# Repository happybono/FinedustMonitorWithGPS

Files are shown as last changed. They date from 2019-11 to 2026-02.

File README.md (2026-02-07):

# FinedustMonitorWithGPS
Fine dust (air pollution) monitoring station. Air pollution monitoring channel updates once every minute with PM 10.0 and PM 2.5 readings from the Nova PM (SDS011) Sensor. Also includes real-time location tracking capabilities using the GY-NEO6MV2 GPS Sensor.

<div align="center">
 



</div>
                                                                                                         
 
### Please note
> [!NOTE]
> This project requires a GY-NEO6MV2 GPS Sensor. For a project that does not require a GPS module, please visit the following link : https://github.com/happybono/FinedustMonitor
 
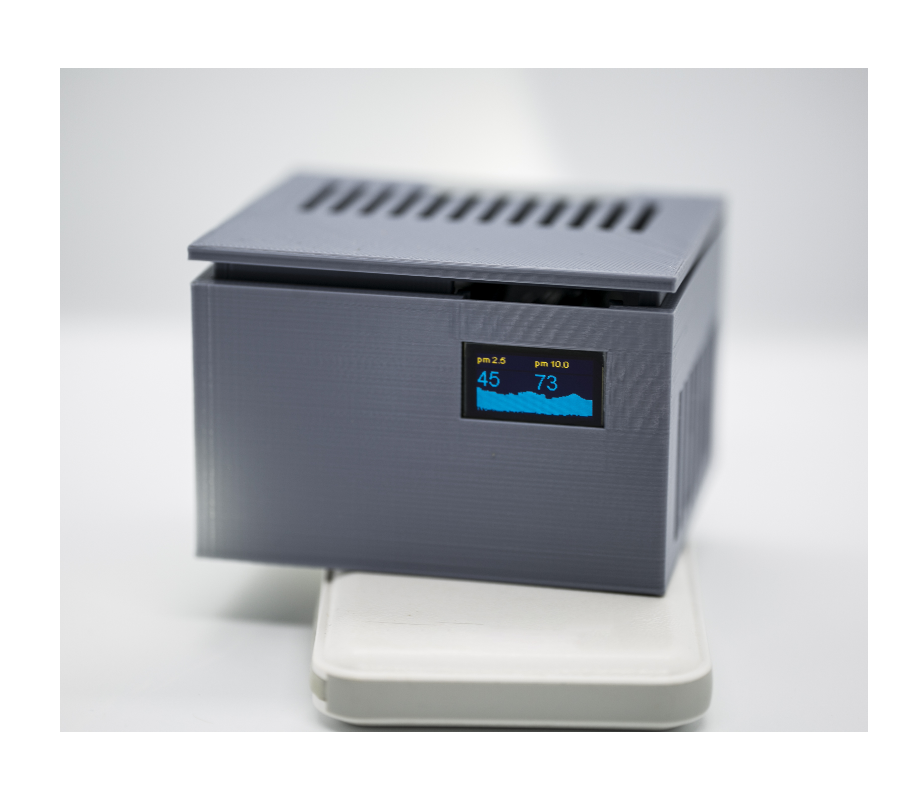
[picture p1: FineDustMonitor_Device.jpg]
Final Product


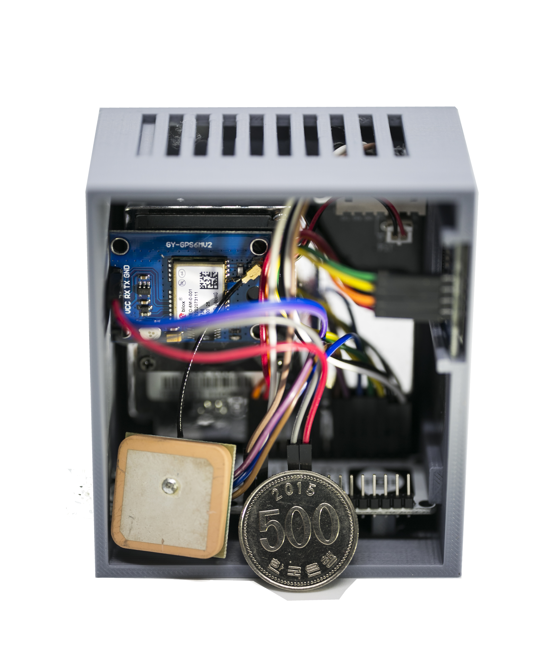
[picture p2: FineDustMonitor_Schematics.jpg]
Final Circuit


## What's New
<details>
<summary>Click to Expand</summary>
  
### v1.0
#### November 24, 2019
> [Initial Release.](https://github.com/happybono/FinedustMonitorWithGPS/commit/aa9cbf7b85308d91ce775d71c36cdd96b5740529)

#### December 16, 2019
> [Read GPS data from ThingSpeak and displays it on Google Maps using ESP12e NodeMCU and GPSNeo6MV2 Module.](https://github.com/happybono/FinedustMonitorWithGPS/blob/master/Maps/GoogleMaps.html "FinedustMonitorWithGPS/Maps/GoogleMaps.html")

#### December 25, 2019
> [Now supports [Channel Status Updates] in ThingSpeak](https//thingspeak.com/channels/920137)  Updated [FinedustMonitorWithGPS.ino](https//github.com/happybono/FinedustMonitorWithGPS/commit/01367946fd2dc10b39b39dec19309892311e92ea "/FinedustMonitorWithGPS/FinedustMonitorWithGPS.ino"), [server.ino](https://github.com/happybono/FinedustMonitorWithGPS/commit/3c3a89e9d8a4e45f591379dc96e2e7b67e15914d "/FinedustMonitorWithGPS/server.ino")

#### December 29, 2019
> [Various bugs fixed.](https://github.com/happybono/FinedustMonitorWithGPS/commit/d6d25d7cf4dc4b91f174259ea1e473220ab79385)

#### January 20, 2020
> ["Latest PM sensor readings" plugin added in ThingSpeak.](https://github.com/happybono/FinedustMonitorWithGPS/tree/master/Plugins/StatusUpdates)

### v2.0
#### January 21, 2020
> [Displays additional information](https://github.com/happybono/FinedustMonitorWithGPS/blob/2882255266a72da46fa2a047b24e56b23cf94838/Plugins/StatusUpdates/CSS.css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) ([temperature](https://github.com/happybono/FinedustMonitorWithGPS/blob/2882255266a72da46fa2a047b24e56b23cf94838/Plugins/StatusUpdates/JavaScript.html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), [latitude](https://github.com/happybono/FinedustMonitorWithGPS/blob/2882255266a72da46fa2a047b24e56b23cf94838/Plugins/StatusUpdates/JavaScript.html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), [longitude](https://github.com/happybono/FinedustMonitorWithGPS/blob/2882255266a72da46fa2a047b24e56b23cf94838/Plugins/StatusUpdates/JavaScript.html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)) in the[ "Latest PM sensor readings" plugin.](https://github.com/happybono/FinedustMonitorWithGPS/tree/master/Plugins/StatusUpdates)<br><br>
>Various bugs fixed.

#### January 24, 2020
> [Added Reverse Geocoding function in Google Maps.](https://github.com/happybono/FinedustMonitorWithGPS/blob/95abbb8ae55be63581fe9892d7d798f0c71eb8e6/Maps/GoogleMaps.html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)<br><br>
> [Optimized loading time for Google Maps.](https://github.com/happybono/FinedustMonitorWithGPS/blob/95abbb8ae55be63581fe9892d7d798f0c71eb8e6/Maps/GoogleMaps.html)

#### Jaunary 25, 2020
> [Added an onclick event to displayed marker in Google Maps.](https://github.com/happybono/FinedustMonitorWithGPS/blob/95abbb8ae55be63581fe9892d7d798f0c71eb8e6/Maps/GoogleMaps.html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)

#### February 05, 2020
> [Added VBA (Visual Basic for Applications) code for reverse geocoding support in Microsoft Excel.](https://github.com/happybono/FinedustMonitorWithGPS/blob/master/Maps/Excel/GEOSage.vb)<br>
> Powered by MSExcel logo<br><br>
> [Added Javascript (.gs) code for reverse geocoding support in Google Sheets.](https://github.com/happybono/FinedustMonitorWithGPS/blob/master/Maps/Excel/GoogleSheets.gs) ([ⓒ 2018 Christos Samaras](https://myengineeringworld.net/2018/08/geocoding-reverse-gas.html))<br>
> [Added Javascript (.gs) code for reverse geocoding macro support in Google Sheets.](https://github.com/happybono/FinedustMonitorWithGPS/blob/master/Maps/Excel/GoogleSheetsGeocodingMacro.gs) ([ⓒ 2016 - 2017 Max Vilimpoc](https://github.com/nuket/google-sheets-geocoding-macro))<br>
> Powered by Google logo

#### February 19, 2020
> [Optimized performance for data processing.](https://thingspeak.com/channels/920137/api_keys)

#### February 20, 2020
> ["Email Alert" function added as a ThingSpeak Analysis plug-in.](https://github.com/happybono/FinedustMonitorWithGPS/blob/master/Plugins/Email/EmailNotifier.m) 

#### February 26, 2020
> [Performance improvements (up to 2× as faster than before) in the ADDRGEOCODE function in GEOSage.vb.](https://github.com/happybono/FinedustMonitorWithGPS/blob/master/Maps/Excel/GEOSage.vb#L86) <br><br>
> [Now supports Unicode using the Microsoft ActiveX Data Objects Library in the ADDRGEOCODE function in GEOSage.vb.](https://github.com/happybono/FinedustMonitorWithGPS/blob/master/Maps/Excel/GEOSage.vb#L115)

#### February 27, 2020
> [Added GEOSage sample files.](https://github.com/happybono/FinedustMonitorWithGPS/tree/master/Maps/Excel) <br>
> GEOSage sample includes Excel files that use demonstration data using Google Maps Geocoding API Key. The 
API key used in this project for geocoding and reverse geocoding features is not provided for your use. 
The mock data demonstrates all functions with static result values as the Google Maps geocoding API Key and 
VBA Add-in code is not included in the GEOSage sample.

#### March 03, 2020
> [Added GEOSage.bas file to support direct import from Microsoft Excel.](https://github.com/happybono/FinedustMonitorWithGPS/blob/master/Maps/Excel/GEOSage.bas)

#### May 28, 2020
> [Added 3D modeled housing file.](https://github.com/happybono/FinedustMonitorWithGPS/blob/master/3DModels/SDS011-Housing.stl)

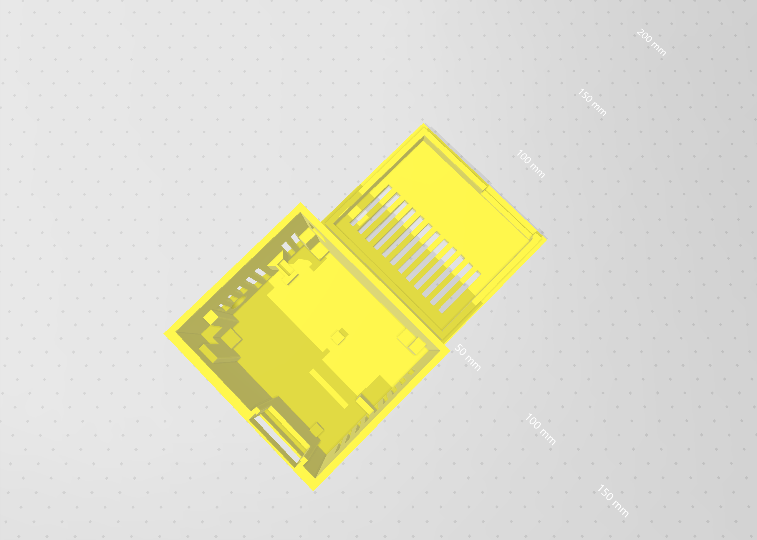
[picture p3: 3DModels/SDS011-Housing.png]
3DModel
> 

#### June 04, 2020
> Attached a programmed NFC Tag Sticker for faster and more convenient access to the ThingSpeak dashboard.

#### June 11, 2020
> [Fine dust (PM 2.5 and PM 10.0) 3D visualization bar charts added on the ThingSpeak dashboard.](https://github.com/happybono/FinedustMonitorWithGPS/tree/master/Plugins/Visualizations)

#### June 12, 2020
> [Various bugs fixed related to fine dust (PM 2.5 and PM 10.0) 3D visualization bar charts.](https://github.com/happybono/FinedustMonitorWithGPS/tree/master/Plugins/Visualizations)

#### June 16, 2020
> [Supports multiple series (PM 2.5 & PM 10.0) chart as a ThingSpeak plugin.](https://github.com/happybono/FinedustMonitorWithGPS/tree/master/Plugins/MultiSeriesChart)

#### June 17, 2020
> Various bugs fixed.

#### June 25, 2020
> [Major improvements to the "Latest PM sensor readings" plugin.](https://github.com/happybono/FinedustMonitorWithGPS/tree/master/Plugins/StatusUpdates)

#### June 27, 2020
> [Various improvements to the "Latest PM sensor readings" plugin.](https://github.com/happybono/FinedustMonitorWithGPS/tree/master/Plugins/StatusUpdates)<br><br>
> [Several bugs fixed related to the "Latest PM sensor readings" plugin.](https://github.com/happybono/FinedustMonitorWithGPS/tree/master/Plugins/StatusUpdates)

#### July 03, 2020
> [Various bugs fixed related to fine dust (PM 2.5 and PM 10.0) 3D visualization bar charts.](https://github.com/happybono/FinedustMonitorWithGPS/tree/master/Plugins/Visualizations)

#### July 08, 2020
> [Fixed a defect that prevented the measurement value from being uploaded under certain environmental conditions.](https://github.com/happybono/FinedustMonitorWithGPS/blob/master/FinedustMonitorWithGPS/FinedustMonitorWithGPS.ino)

#### July 15, 2020
> [Temperature 3D visualization bar charts added on the ThingSpeak dashboard.](https://github.com/happybono/FinedustMonitorWithGPS/tree/master/Plugins/Visualizations)

#### December 07, 2020
> [Applied font styling to the "Latest PM sensor readings" plugin.](https://github.com/happybono/FinedustMonitorWithGPS/tree/master/Plugins/StatusUpdates)<br><br>
> [Adjusted code formatting and indentation (if applicable).](https://github.com/happybono/FinedustMonitorWithGPS/tree/master/Plugins/StatusUpdates)

#### December 08, 2020
> [Improved readability of symbols and measurement units.](https://github.com/happybono/FinedustMonitorWithGPS/tree/master/Plugins/StatusUpdates)

#### December 27, 2020
> ["Geocoder failed due to: ZERO_RESULTS" error output changed. The error message is no longer displayed in the pop-up message box, will display it in the "Latest PM sensor readings" plugin as text.](https://github.com/happybono/FinedustMonitorWithGPS/tree/master/Plugins/StatusUpdates)

#### December 30, 2020
> [Various bugs fixed.](https://github.com/happybono/FinedustMonitorWithGPS/blob/master/FinedustMonitorWithGPS/FinedustMonitorWithGPS.ino)

### v3.0
#### January 11, 2021
> [Now supports notifications through Twitter using the Thingtweet plugin from the ThingSpeak platform.](https://www.twitter.com/Jeongwang3D_AQI)

#### March 28, 2021
> [Now supports analyzing and drawing charts on https://thingspeak.com/channels/1184617. Shown are the weekly average values (PM 2.5, PM 10.0, and temperature) using data from https://thingspeak.com/channels/920137.](https://github.com/happybono/FinedustMonitorWithGPS/commit/a3c0b472f2549ebac2ff92c9009388211a50a09a)
 
#### April 22, 2021
> [Added Twitter timeline widget as a JavaScript-based plug-in.](https://github.com/happybono/FinedustMonitorWithGPS/tree/b334c427448ce27f469f366334dc8303b18c8db3/Plugins/TwitterTimeline)

#### August 23, 2021
> [Improvements have been made to the "Email Alert" function.](https://github.com/happybono/FinedustMonitorWithGPS/blob/master/Plugins/Email/EmailNotifier.m) 
  
#### April 16, 2022
> [Update to support tightened the rules around query parameters in the ThingSpeak platform.](https://github.com/happybono/FinedustMonitorWithGPS/commit/42160c6df4b8b7759f6b9ec417fe9858e86d11a1)

#### March 26, 2025
> [Applied text flipping animation to the "Latest PM sensor readings" plugin.](https://github.com/happybono/FinedustMonitorWithGPS/tree/master/Plugins/StatusUpdates)
</details>

#### December 25, 2025
> [Changed image source to blog URL to resolve imread() access issue.](https://github.com/happybono/FinedustMonitorWithGPS/commit/5cb7dc2b1ca8dca2396561faf552fcb2dcdea0da)

## Specifications
### Scenarios
* Measuring the fine dust contamination level in the air in real time. The value is displayed on the OLED Screen and updated every second.
* Measuring the current temperature.
* Track and update device location in real time.
* Reading GPS data (longitude, latitude) from [ThingSpeak](https://thingspeak.com/channels/920137) and display it using [Google Maps](https://www.google.com/maps/) with the [Maps JavaScript API](https://developers.google.com/maps/documentation/javascript/tutorial).
* Refining data and synchronizing with the web-based cloud service. (i.e. [ThingSpeak](https://www.thingspeak.com/), [Plaive](https://plaive.10make.com/))
* Refining the average calculated data to separate channels on the web-based cloud service. (i.e. [ThingSpeak](https://www.thingspeak.com/), [Plaive](https://plaive.10make.com/))
* Using reverse geocoding to convert a location (latitude, longitude) measured by the device to a readable address.
* Using [Microsoft Excel](https://products.office.com/get-started-with-office-2019) to process a batch of locations (latitude, longitude). Data can be exported in CSV format from [ThingSpeak](https://www.thingspeak.com/) to open in Excel.

#### What is Reverse Geocoding?
> Reverse geocoding is the process of back (reverse) coding of a point location (latitude, longitude) to a readable address or place name. This permits the identification of nearby street addresses, places, and/or areal subdivisions such as neighbourhoods, counties, states, or countries.

[More information on reverse geocoding with Google Maps JavaScript API](https://developers.google.com/maps/documentation/geocoding/intro#ReverseGeocoding)
<br>
Powered by Google logo

### Connections
* 1 x Micro-USB

### Wireless
* IEEE 802.11 b/g/n Wi-Fi technology.

### Battery life 
* Up to 35 hours (1 day and 12 hours) of typical device usage.
* Testing consisted of full-time active use until complete battery discharge. 
* Wi-Fi was connected to a network.
* Syncs data once every minute with PM 10.0 and PM 2.5 readings from the Nova PM (SDS011) Sensor, Temperature reading from the DS18B20 Temperature Sensor, and GPS-positioned reading values (longitude, latitude) from the GY-NEO6MV2 GPS Sensor.
* Battery life may vary significantly with settings, usage, and other factors.

## Apparatus (Equipment)
### Platform
* NodeMCU ESP8266-12E

### SDS011 Dust Sensor
* Soldering required
* D1 : TX of SDS011

### 0.96" SSD1306 I2C OLED Display 
* Soldering required
* D3 : Data, D2 : Clock

### GY-NEO6MV2 GPS Sensor
* Soldering required
* D6 & D7 : TX & RX of GY-NEO6MV2 respectively.

### DS18B20 Temperature Sensor (Thermometer)
* Soldering required
* D4 : Data

### iriver Tactile (SPB-10000) Portable Battery
* USB Port : Power
* Micro-USB : Charging Port
* Dimension : 63.3 mm (W) × 90.7 mm (D) × 22.3 mm (H)
* Weight : 180 g
* Input : DC-5V / 2A (Micro 5-Pin)
* Output : DC-5V / 2A (2 USB ports)
* Capacity : 10,000 mAh

### Circular NFC Tag Sticker (N-Tag 216)
* Size : 25.0 mm
* Capacity : 926 Byte
* This should be programmed to automatically open the ThingSpeak Dashboard when the NFC-capable device comes into contact with the NFC Tag Sticker.
* https://www.amazon.com/GoToTags-Blank-White-Metal-NFC/dp/B00TRL774A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

## Schematics
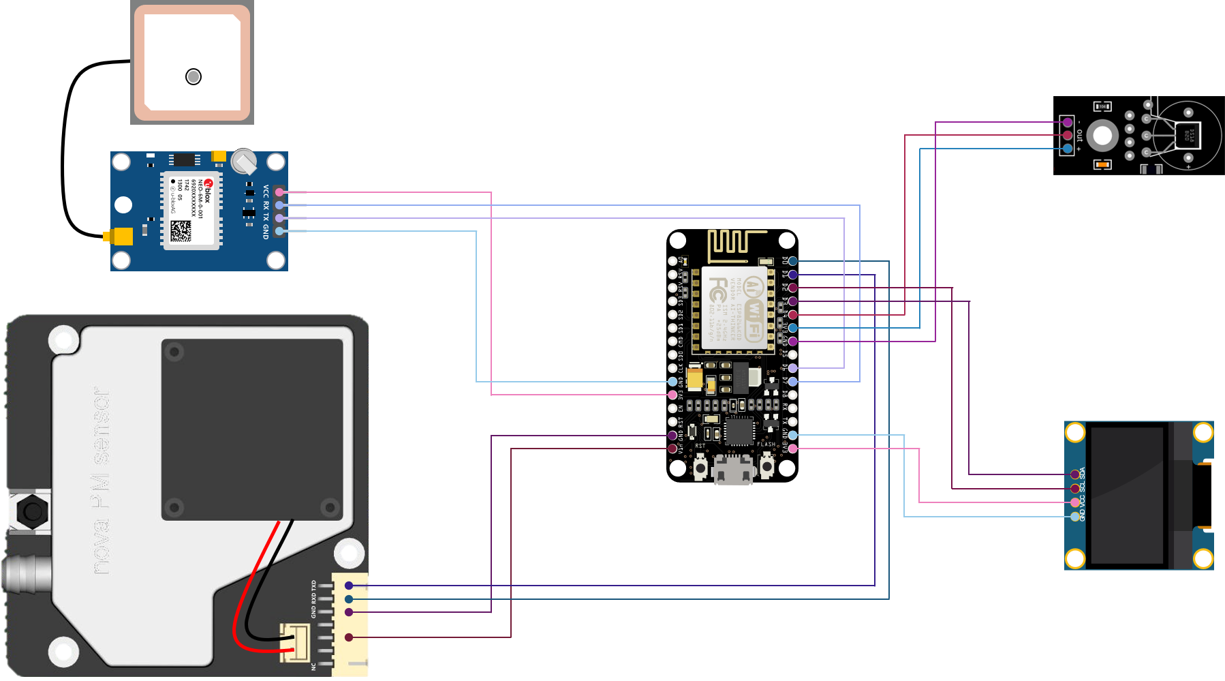
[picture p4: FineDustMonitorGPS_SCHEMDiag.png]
Schematics Diagram


## Data Refinement / Synchronization
### ThingSpeak
* ThingSpeak (https://thingspeak.com/channels/920137)
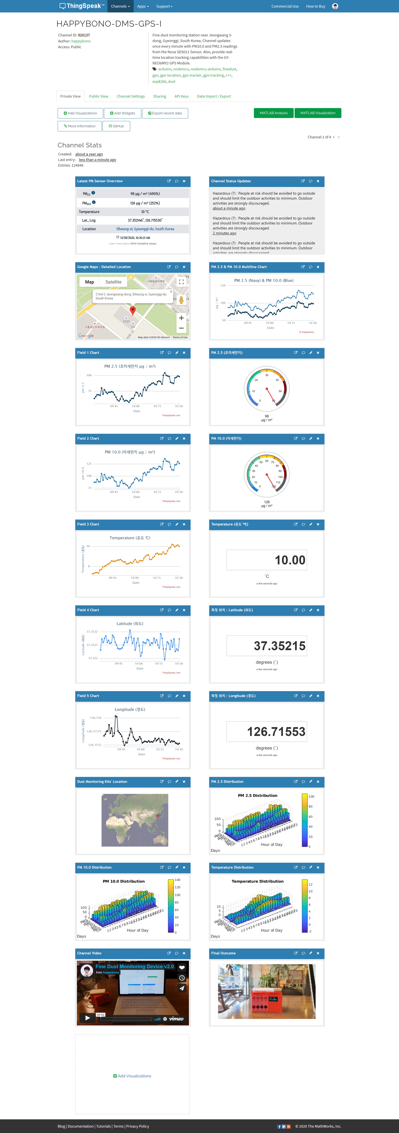
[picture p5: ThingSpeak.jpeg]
ThingSpeak Screenshot

  
### Plaive
* Plaive (https://plaive.10make.com/)
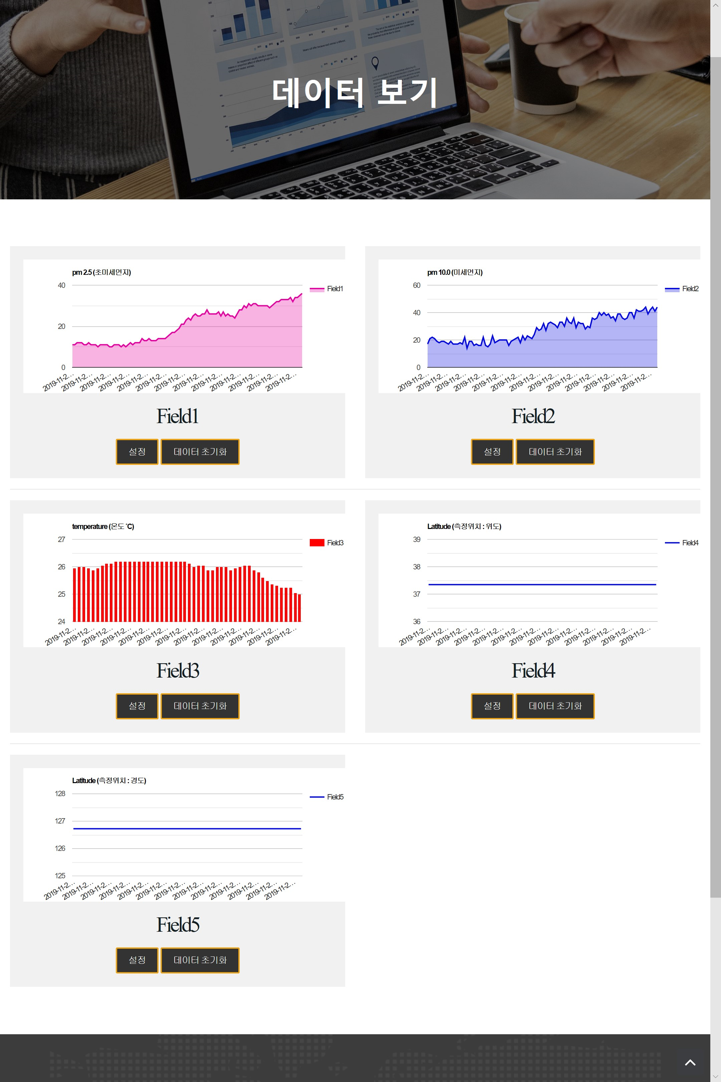
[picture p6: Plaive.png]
Plaive Screenshot


## Libraries Used
### DallasTemperature
This library supports the following devices :

DS18B20 <br>
DS18S20 - Please note there appears to be an issue with this series. <br>
DS1822 <br>
DS1820 <br>
MAX31820 <br>
https://github.com/milesburton/Arduino-Temperature-Control-Library

### TinyGPSPlus (TinyGPS++) for GY-NEO6MV2
A new, customizable Arduino NMEA parsing library. A NEW Full-featured GPS/NMEA Parser for Arduino TinyGPS++ is a new Arduino library for parsing NMEA data streams provided by GPS modules.

Like its predecessor, TinyGPS, this library provides compact and easy-to-use methods for extracting position, date, time, altitude, speed, and course from consumer GPS devices.<br>
https://github.com/mikalhart/TinyGPSPlus

### SSD1306 (0.96") OLED Display
This is a driver for SSD1306 128x64, 128x32, 64x48, and 64x32 OLED displays running on the Arduino / ESP8266 & ESP32 and mbed-os platforms. Can be used with either the I2C or SPI version of the display. <br>
https://www.github.com/ThingPulse/esp8266-oled-ssd1306

### RunningMedian
Arduino library to determine the running median utilizing a circular buffer. <br>
https://github.com/RobTillaart/Arduino/tree/master/libraries/RunningMedian

Running Median looks like a running average with a small but important twist.   
**Running average** **averages** the last `N` samples, while the **running median** takes the last `N` samples, **sorts them, and takes the middle one, or the average of the middle two**.

> [!Important]
> Important differences between **running average** and **running median** :
> * **Running median** will return real data (e.g., a real sample from a sensor) if one uses an odd size of the buffer (preferred). Running average may return a value that is never sampled.
> * **Running median** will give zero weight to outliers, and 100% to the middle sample, whereas running average gives the same weight to all samples.
> * **Running median** will often give constant values for some time.
> * As one knows, the values in the buffer, one can predict to some extent how much the next samples will change the **running median**.
> * **Running median** is a bit harder as one needs to keep the values to remove the oldest and keep them sorted to be able to select the median.

## References
* Christos Samaras 2018, Geocoding & Reverse Geocoding Functions In Google Sheets, My Engineering World, Christos Samaras, viewed 5 February 2020, <https://myengineeringworld.net/2018/08/geocoding-reverse-gas.html>.
* Max Vilimpoc 2019, nuket/google-sheets-geocoding-macro, GitHub, Nuket. viewed 5 February 2020, <https://github.com/nuket/google-sheets-geocoding-macro>.
* Rob Tillaart 2018, RobTillaart/Arduino, GitHub, RobTillaart, viewed 23 February 2020, <https://github.com/RobTillaart/Arduino/blob/master/libraries/RunningMedian/RunningMedian.cpp>.
* ThingPulse 2020, ThingPulse/esp8266-oled-ssd1306, GitHub, ThingPulse, viewed 24 November 2019, <https://github.com/ThingPulse/esp8266-oled-ssd1306>.

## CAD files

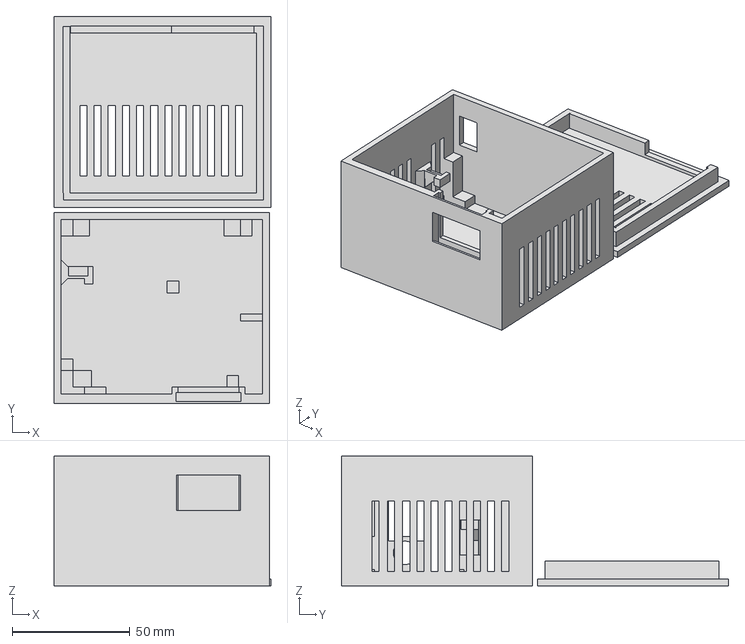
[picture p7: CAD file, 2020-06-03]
3DModels/SDS011-Housing.3mf
92.0 x 164.2 x 55.0 mm

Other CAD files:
3DModels/SDS011-Housing.stl

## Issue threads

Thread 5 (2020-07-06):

New Login Requirement for Free Accounts Using MATLAB Analysis

happybono, 2020-07-06:
For accounts with a free license, extended inactivity disables execution of MATLAB® Analysis. For a MATLAB Analysis App associated with TimeControl and React apps, you need to log in to ThingSpeak™ at least once every 60 days to ensure they continue to execute without interruption.

https://www.mathworks.com/help/thingspeak/release-notes.html
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

happybono, 2020-07-06:
For a MATLAB Analysis App associated with TimeControl and React apps, **you need to log in to ThingSpeak™ at least once every 60 days to ensure they continue to execute without interruption.**

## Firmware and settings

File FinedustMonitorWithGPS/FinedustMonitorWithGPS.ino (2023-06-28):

//
//    FILE: FinedustMonitorWithGPS.ino
//  AUTHOR: Jaewoong Mun (happybono@outlook.com)
// CREATED: November 19, 2019
//
// Released to the public domain
//

#include <TinyGPS++.h>
#include <SoftwareSerial.h>
TinyGPSPlus gps;
SoftwareSerial ss(12, 13);
SoftwareSerial dust(D1, D0, false, 256);            //RX, TX Communication
#include "RunningMedian.h"

RunningMedian pm25s = RunningMedian(19);
RunningMedian pm10s = RunningMedian(19);

char* ssid = "[Wi-Fi SSID]";
char* password = "[Wi-Fi Password]";
String api_key = "[ThingSpeak Write API Key]";

//#define PLAIVE_SERVER_ENABLE
#define THINGSPEAK_SERVER_ENABLE

boolean wifi_ready;
float map_x, map_y;
String s_map_x, s_map_y, status;
int pm25i, pm10i;

//초기 세팅 (Initialize.)
void setup() {
  Serial.begin(115200);
  dust.begin(9600);
  ss.begin(9600);
  setup_oled();
  wifi_ready = connect_ap(ssid, password);
  
  if (!wifi_ready) nowifi_oled();

  Serial.println("\nFinedust Sensor Box V3.2, 2022/04/16 HappyBono");
}


void got_dust(int pm25, int pm10) {                 //formula for dust sensor just use!!
  pm25 /= 10;
  pm10 /= 10;
  pm25s.add(pm25);
  pm10s.add(pm10);
  do_oled(pm25, pm10);                              //print pm25, pm10 in oled
}


//서버에 데이터 보내기 (Sending collected data to server.)
void do_interval() {
  if (wifi_ready) {
#ifdef PLAIVE_SERVER_ENABLE
    do_server_plaive(api_key, int(pm25s.getMedian()), int(pm10s.getMedian()), get_temperature(), s_map_x, s_map_y);
#else
#ifdef THINGSPEAK_SERVER_ENABLE
    Serial.println("dst: pm25=" + String(int(pm25s.getMedian())) + " / pm10=" + String(int(pm10s.getMedian())) + "/ s=" + String(status));
    do_server_thingspeak(api_key, int(pm25s.getMedian()), int(pm10s.getMedian()), get_temperature(), s_map_x, s_map_y, status);
#else
    do_server_default(api_key, int(pm25s.getMedian()), int(pm10s.getMedian()), get_temperature(), s_map_x, s_map_y);
#endif
#endif
  }                                                    //wifi is ok
}

unsigned long mark = 0;
boolean got_interval = false;

//아두이노가 반복적으로 작동하는 부분 (Where Arduino works repeatedly.)
void loop() {
  if (ss.available() <= 0) {
    // Serial.println("SIGNAL STATUS : WEAK");
    s_map_x = String(map_x, 6);
    s_map_y = String(map_y, 6);
  }
  else {
    while (ss.available() > 0) {
      //Serial.println("SIGNAL STATUS : GREAT");
      if (gps.encode(ss.read())) {
        //Serial.println("GPS READ");
        Serial.println(ss.read());
        if (gps.location.isValid()) {
          //Serial.println("LOCATION : GREAT");
          map_x = gps.location.lat();
          map_y = gps.location.lng();
          Serial.println(String(map_x, 6));
          Serial.println(String(map_y, 6));
        }
      }
      s_map_x = String(map_x, 6);
      s_map_y = String(map_y, 6);
      yield();
    }
  }
  while (dust.available() > 0) {
    do_dust(dust.read(), got_dust);
    yield();                                          //loop 에서 while 문을 사용하는 경우 yield 를 포함해주어야 합니다.

    //Serial.println(map_x);
    //Serial.print("pm 10 : ");
    //Serial.println(int(pm10s.getMedian()));

    /* AQI (실시간 대기질 지수) 등급 분류를 위한 코드입니다.
       실시간 대기질 기준 수치는 국제 표준인 WHO 대기질 수치 기준으로 계산하였습니다.

       http://www.euro.who.int/__data/assets/pdf_file/0005/78638/E90038.pdf
       https://airnow.gov/index.cfm?action=aqibasics.aqi */


    // 초미세먼지 AQI (실시간 대기질 지수) 등급을 분류합니다.
    //   0 이상   8 이하 : 1
    //   9 이상  16 이하 : 2
    //  17 이상  26 이하 : 3
    //  27 이상  34 이하 : 4
    //  35 이상  43 이하 : 5
    //  44 이상  51 이하 : 6
    //  52 이상  ∞  이하 : 7

    int pm25m = int(pm25s.getMedian());

    if (pm25m < 9) {
      pm25i = 1;
    } else if (pm25m < 17) {
      pm25i = 2;
    } else if (pm25m < 27) {
      pm25i = 3;
    } else if (pm25m < 35) {
      pm25i = 4;
    } else if (pm25m < 44) {
      pm25i = 5;
    } else if (pm25m < 52) {
      pm25i = 6;
    } else {
      pm25i = 7;
    }

    // 미세먼지 AQI (실시간 대기질 지수) 등급을 분류합니다.
    //   0 이상  16 이하 : 1
    //  16 이상  31 이하 : 2
    //  32 이상  51 이하 : 3
    //  52 이상  68 이하 : 4
    //  69 이상  84 이하 : 5
    //  85 이상 101 이하 : 6
    // 102 이상  ∞  이하 : 7

    int pm10m = int(pm10s.getMedian());

    if (pm10m < 16) {
      pm10i = 1;
    } else if (pm10m < 32) {
      pm10i = 2;
    } else if (pm10m < 52) {
      pm10i = 3;
    } else if (pm10m < 69) {
      pm10i = 4;
    } else if (pm10m < 85) {
      pm10i = 5;
    } else if (pm10m < 102) {
      pm10i = 6;
    } else {
      pm10i = 7;
    }
    
    /* ThingSpeak 채널 내 Status Update (상태 업데이트) 영역에 표시되는 문구이므로,
        종합적인 정보 표현을 위해 초미세먼지와 미세먼지 등급을 비교 한 후
        두 가지 중 높은 등급 기준으로 경고 혹은 권고메시지를 표시합니다. */

    // 가령, 분류된 초미세먼지 등급이 미세먼지 등급보다 같거나 높은 경우, 초미세먼지 등급을 기준으로 내용을 표시하기 위하여 아래의 문자열을 status 변수에 저장합니다.

    switch ((pm25i >= pm10i) ? pm25i : pm10i) {
      case 1:
        status = "Excellent%20(1)%20:%20The%20air%20quality%20is%20excellent.%20As%20air%20pollution%20poses%20no%20threat,%20conditions%20are%20ideal%20for%20outdoor%20activities.";
        break;

      case 2:
        status = "Very%20Good%20(2)%20:%20The%20air%20quality%20is%20very%20good.%20As%20air%20pollution%20poses%20little%20or%20no%20risk,%20conditions%20very%20good%20for%20outdoor%20activities.";
        break;

      case 3:
        status = "Moderate%20(3)%20:%20Air%20quality%20is%20acceptable.%20however,%20for%20some%20pollutants,%20there%20may%20be%20a%20moderate%20health%20concern%20for%20specific%20people%20who%20are%20unusually%20sensitive%20to%20air%20pollution.";
        break;

      case 4:
        status = "Satisfactory%20(4)%20:%20Members%20of%20sensitive%20groups%20may%20experience%20health%20effects,%20other%20people%20should%20limit%20spending%20time%20outdoors,%20especially%20when%20they%20experience%20symptoms%20such%20as%20cough%20or%20sore%20throat.";
        break;

      case 5:
        status = "Bad%20(5)%20:%20Everyone%20may%20begin%20to%20experience%20health%20effects,%20members%20of%20sensitive%20groups%20may%20experience%20more%20serious%20health%20effects.%20Not%20recommended%20for%20outdoor%20activities.";
        break;

      case 6:
        status = "Severe%20(6)%20:%20Everyone%20may%20experience%20more%20serious%20health%20effects.%20People%20at%20risk%20should%20be%20avoided%20to%20go%20outside%20and%20should%20limit%20outdoor%20activities%20to%20a%20minimum.%20Outdoor%20activities%20are%20discouraged.";
        break;

      case 7:
        status = "Hazardous%20(7)%20:%20People%20at%20risk%20should%20avoid%20going%20outside%20and%20should%20limit%20outdoor%20activities%20to%20a%20minimum.%20Outdoor%20activities%20are%20strongly%20discouraged.";
        break;
    }

    //Serial.println("PM2.5 = " + String(int(pm25s.getMedian())) + " / " + String(pm25i));
    //Serial.println("PM10.0  = " + String(int(pm10s.getMedian())) + " / " + String(pm10i));
  }

  if (millis() > mark) {                          //one minute (60000) interval
    mark = millis() + 60000;
    got_interval = true;
  }

  if (got_interval) {
    got_interval = false;
    do_interval();
  }
  yield();
}

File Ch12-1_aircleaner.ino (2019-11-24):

#include <ESP8266WiFi.h>
#include <PubSubClient.h>

#define AIR_PIN 14

const char* ssid = "                       ";
const char* password = "                         ";
const char* mqtt_server = "13.209.250.27";
const char* topic = "speak_topic";

WiFiClient espClient;
PubSubClient client(espClient);

long lastMsg = 0;
char msg[50];
int value = 0;

void setup_wifi() {
  delay(10);
  Serial.println();
  Serial.print("Connecting to ");
  Serial.println(ssid);

  WiFi.begin(ssid, password);

  while (WiFi.status() != WL_CONNECTED) {
    delay(500);
    Serial.print(".");
  }

  randomSeed(micros());

  Serial.println("");
  Serial.println("WiFi connected");
  Serial.println("IP address: ");
  Serial.println(WiFi.localIP());
}

void callback(char* topic, byte* payload, unsigned int length) {
  String final_string;

  Serial.print("Message arrived [");
  Serial.print(topic);
  Serial.print("] ");
  for (int i = 0; i < length; i++) {
    Serial.print((char)payload[i]);
    final_string += (char)payload[i];  
  }
 
  Serial.println();
  Serial.println("-----------------------------------------");
  Serial.println(final_string);
  // Switch on the LED if an 1 was received as first character
  // fix it - magiceco//
  if (final_string == "1") {
    //digitalWrite(BUILTIN_LED, LOW);   // Turn the LED on (Note that LOW is the voltage level
    digitalWrite(AIR_PIN, LOW);
    // but actually the LED is on; this is because
    // it is acive low on the ESP-01)
  } 
  else if(final_string == "2") {
    //digitalWrite(BUILTIN_LED, HIGH);// Turn the LED off by making the voltage HIGH 
    digitalWrite(AIR_PIN, HIGH);
  }

}

void reconnect() {
  // Loop until we're reconnected
  while (!client.connected()) {
    Serial.print("Attempting MQTT connection...");
    // Create a random client ID
    String clientId = "ESP8266Client-";
    clientId += String(random(0xffff), HEX);
    // Attempt to connect
    if (client.connect(clientId.c_str())) {
      Serial.println("connected");
      // Once connected, publish an announcement...
      client.publish("outTopic", "hello world");
      // ... and resubscribe
      client.subscribe(topic);
    } else {
      Serial.print("failed, rc=");
      Serial.print(client.state());
      Serial.println(" try again in 5 seconds");
      // Wait 5 seconds before retrying
      delay(5000);
    }
  }
}

void setup() {
  Serial.begin(115200);
  pinMode(AIR_PIN, OUTPUT);
  digitalWrite(AIR_PIN, LOW);
  setup_wifi();
  client.setServer(mqtt_server, 1883);
  client.setCallback(callback);
}

void loop() {
  if (!client.connected()) {
    reconnect();
  }
  client.loop();
  long now = millis();
  if (now - lastMsg > 2000) {
    lastMsg = now;
    ++value;
    snprintf (msg, 75, "hello world #%ld", value);
    Serial.print("Publish message: ");
    Serial.println(msg);
    client.publish("outTopic", msg);
  }
}

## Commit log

2019-12-25 Update FinedustMonitorWithGPS.ino
    Bug fixes.
    [FinedustMonitorWithGPS.ino]
2020-07-14 Create Temperature Distribution.m
2020-07-21 Update Temperature Distribution.m
